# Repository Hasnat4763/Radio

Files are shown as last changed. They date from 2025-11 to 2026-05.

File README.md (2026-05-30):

# Akash Chowa DX

Akash Chowa DX is a SW/MW/LW receiver designed based on the Si4735 Radio receiver IC paired with the RP2040 Zero Dev board.

# Why did I build it?

I had an affection towards Radios from childhood. I sometimes try to receive SW stations on my 5$ budget radio I had gotten from a local store. But It does not work that efficiently and I needed a better receiver.
Also the radio I currently have can not demodulate SSB (Single Sideband) and RDS transmitted by modern FM stations. So I designed it to fulfill my own requirements. It also helped me learn new things like impedance control.

# Gallery

Here are some pictures of what I designed

# Schematic

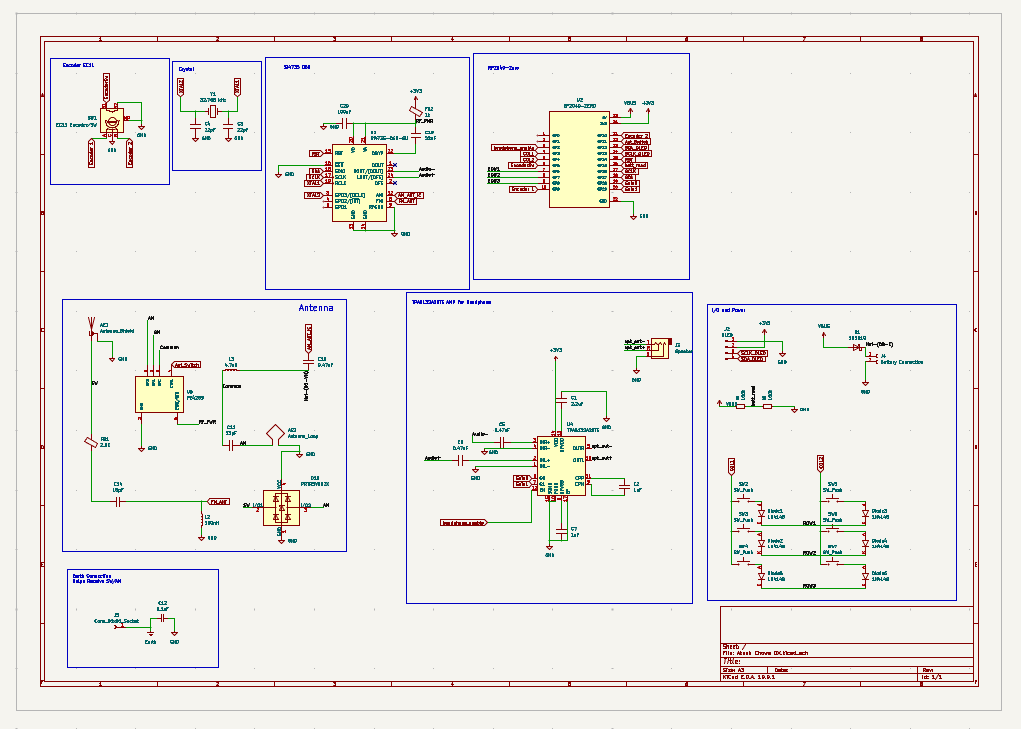
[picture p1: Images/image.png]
Schematic


# PCB

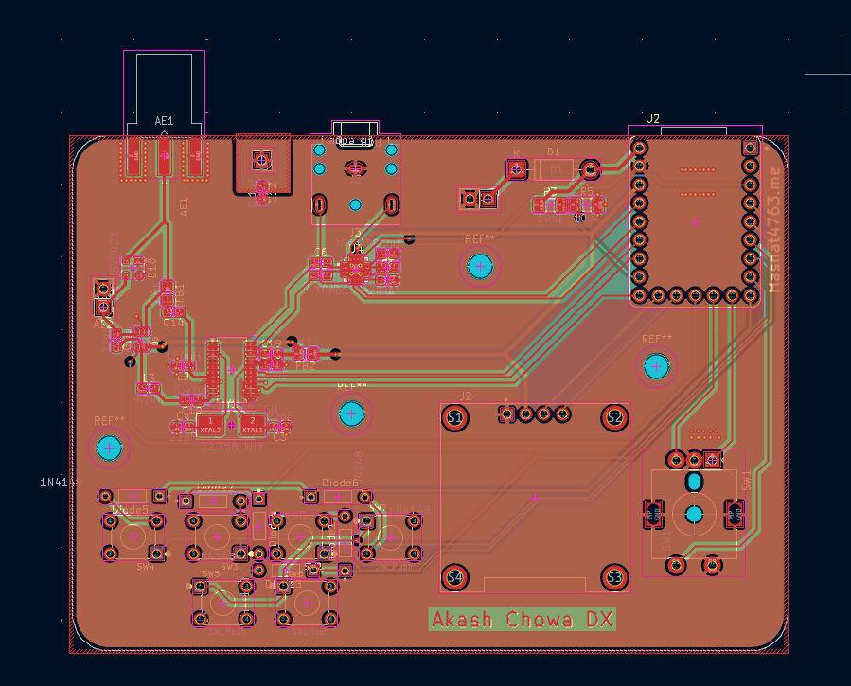
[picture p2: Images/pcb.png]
PCB


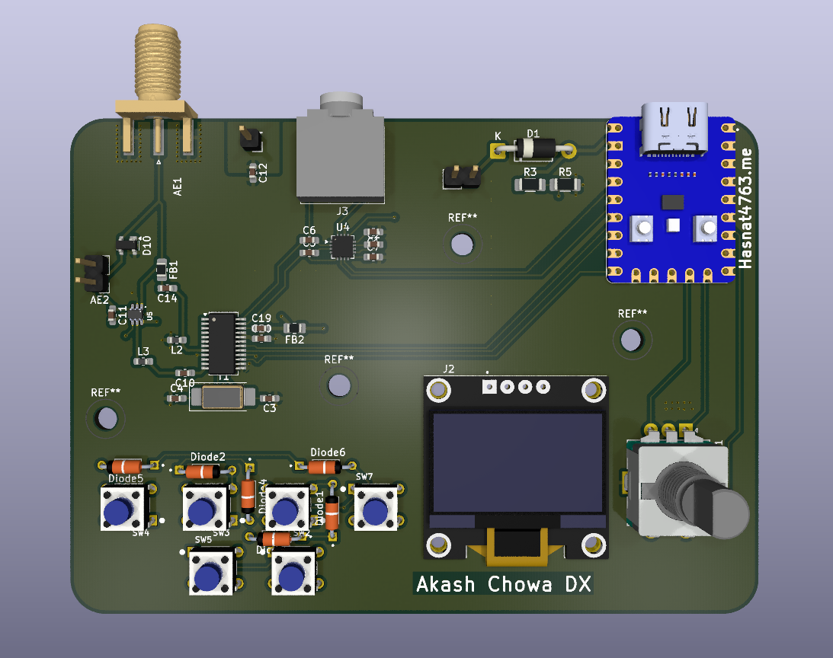
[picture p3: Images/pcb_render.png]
PCB 3D render


# CAD

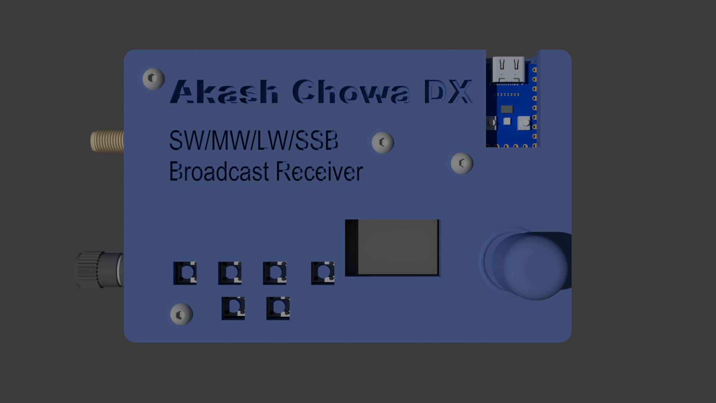
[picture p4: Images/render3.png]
CAD 3D render


Base of the case

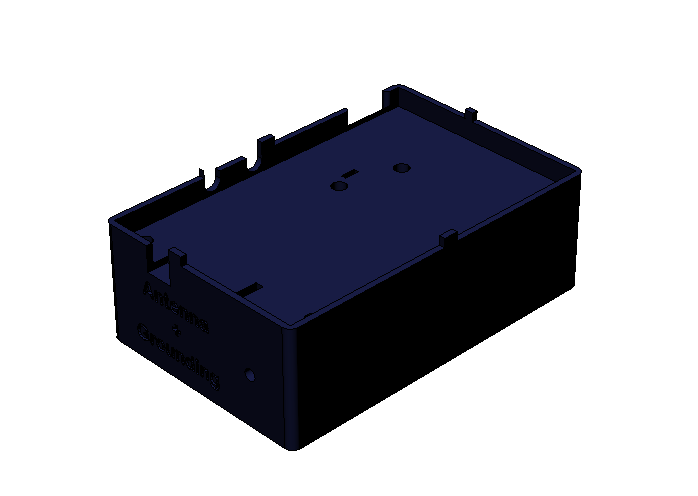
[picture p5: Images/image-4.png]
base


battery cover

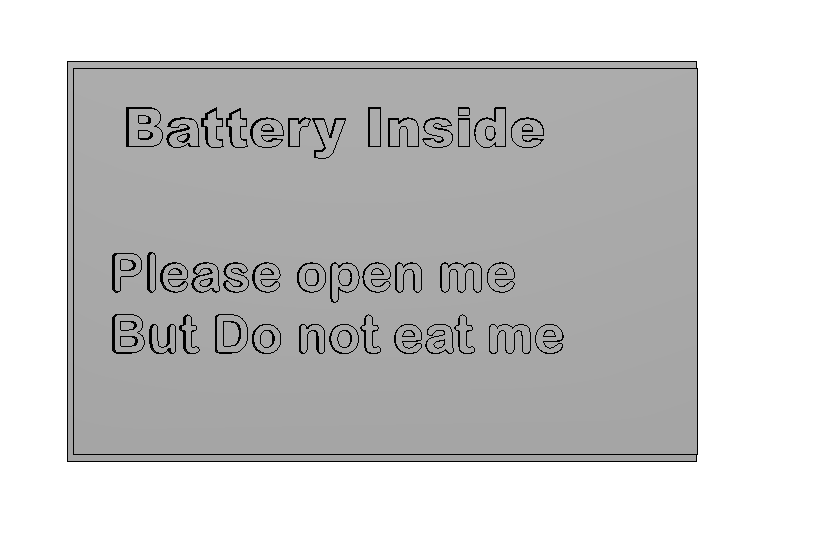
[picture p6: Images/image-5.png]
battery cover


top cover

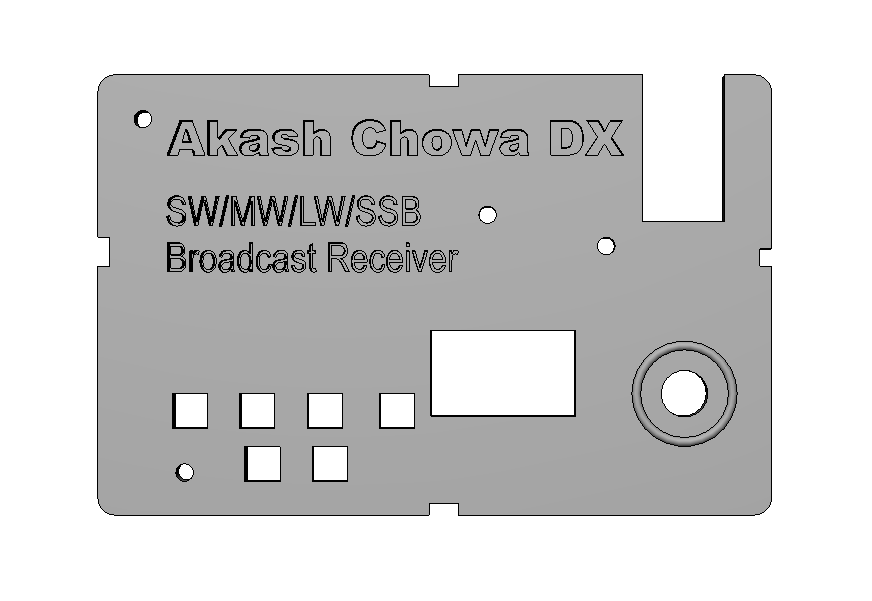
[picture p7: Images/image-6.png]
top cover


# BOM (in progress)

| Item | Quantity | Price | Link |
|---|---|---|---|
| Waveshare RP2040 Zero | 1 | $5.86 | [Link](https://www.aliexpress.com/item/1005009026492881.html) |
| 1N5819 Diode | 100 | $5.49 | [Link](https://www.aliexpress.com/item/1005010374297754.html) |
| 1N4148 Diode | 100 | $4.43 | [Link](https://www.aliexpress.com/item/1005010373909049.html) |
| SSD1306 OLED Display | 1 | $5.33 | [Link](https://www.aliexpress.com/item/1005006141235306.html) |
| EC 11 Encoder with Push Button Half Handle 20MM Shaft | 5 | $6.31 | [Link](https://www.aliexpress.com/item/1005005983134515.html) |
| Si4735 D60 GU | 1 | $15.52  | [Link](https://www.aliexpress.com/item/1005007992766374.html)|
| PE4259 | 20 | $4.96  | [Link](https://www.aliexpress.com/item/32860670352.html)|
| 32.768 kHz Crystal SMD | 10 | $5.01  | [Link](https://www.aliexpress.com/item/1005007548931959.html)|
| CM1213A-01SO | 20 | $6.09  | [Link](https://www.aliexpress.com/item/1005010362089021.html)|
| PAM8302A | 10 | $4.15  | [Link](https://www.aliexpress.com/item/1005011807938839.html)|
| LM4910MM | 5 | $11.43  | [Link](https://www.aliexpress.com/item/1005008963839272.html)|
| 2.5K Ferrite Bead | 100 | $1.63  | [Link](https://www.aliexpress.com/item/1005009841998170.html)|
| 1K Ferrite Bead | 100 | $1.70  | [Link](https://www.aliexpress.com/item/1005009841998170.html)|
| 100uF, 10uF, 100nF, 22pF, 1uF, 0.47uF, 33pF, 18pF, 22nF Capacitor Pack | 720 | $6.21  | [Link](https://www.aliexpress.com/item/1005006124283234.html)|
| 100 ohm Resistor 1206 | 100 | $1.61  | [Link](https://www.aliexpress.com/item/1005011924690352.html)|
| 20k ohm Resistor 1206 | 100 | $1.61  | [Link](https://www.aliexpress.com/item/1005011924690352.html)|
| 100k ohm Resistor 1206 | 100 | $1.61  | [Link](https://www.aliexpress.com/item/1005011924690352.html)|
| SMA connector Edge Mount | 5 | $5.32  | [Link](https://www.aliexpress.com/item/1005007424915378.html)|
| 180nH Inductor 0603 | 100 | $1.33  | [Link](https://www.aliexpress.com/item/1005004900337516.html)|
| 4.7uH Inductor 0603 | 100 | $1.33  | [Link](https://www.aliexpress.com/item/1005004900337516.html)|
| Tactile Switches Push buttons | 20 | $4.12  | [Link](https://www.aliexpress.com/item/1005006046180384.html)|
| 18650 Lithium Battery | 2 | BDT 510 (~$4.16)  | [Link](https://store.roboticsbd.com/battery-charger/983-18650-generic-37v-li-ion-battery-standard-quality-flat-top-solderable-robotics-bangladesh.html)|
| TP4056 BMS | 1 | $4.02 | [Link](https://www.aliexpress.com/item/1005009635476640.html)|
| Rocker Switch | 5 | $5.20  | [Link](https://www.aliexpress.com/item/1005008778176373.html)|
| Binding Post | 5 | $6.00 | [Link](https://www.aliexpress.com/item/1005008274414247.html)|
| Headphone Connector | 10 | $4.45 | [Link](https://www.aliexpress.com/item/32871877936.html)|
| M3 Heat Set Inserts | 30 | $6.13 | [Link](https://www.aliexpress.com/item/1005006071488810.html) |
| M3 Fasteners | 50 | $6.28 | [Link](https://www.aliexpress.com/item/1005011845940916.html) |
| Top Case | 1 | Printing Legion |  |
| Bottom Case | 1 | Printing Legion |  |
| Battery Cover | 1 | Printing Legion | |
| PCB | 5 | $27.67 | JLCPCB |

# Build/Usage Instruction

For impedance control, while ordering from JLCPCB, select the JLC04161H-7628 layer stackup. Also better to import this to the Easyeda Pro and then order as that can get you a few extra discounts.

For ordering parts, you can find most components in LCSC but some components may not be available in LCSC so it needs to be bought from 3rd party stores like aliexpress/alibaba.

For the AM antenna its better to source it from an old broken radio, as its hard to find ferrite antennas online. 

You need a 9:1 Balun to match the impedance of the SMA feed with the long wire antenna you are using.

Never use the Radio while its plugged into the Mains as it introduces extra noise.

For grounding you may be able to just lay the wire parallel to the ground for a few meters.

# Flashing the firmware

To flash the firmware, you first need to add the board to your arduino IDE.

After getting into the Arduino IDE, Go to Preference
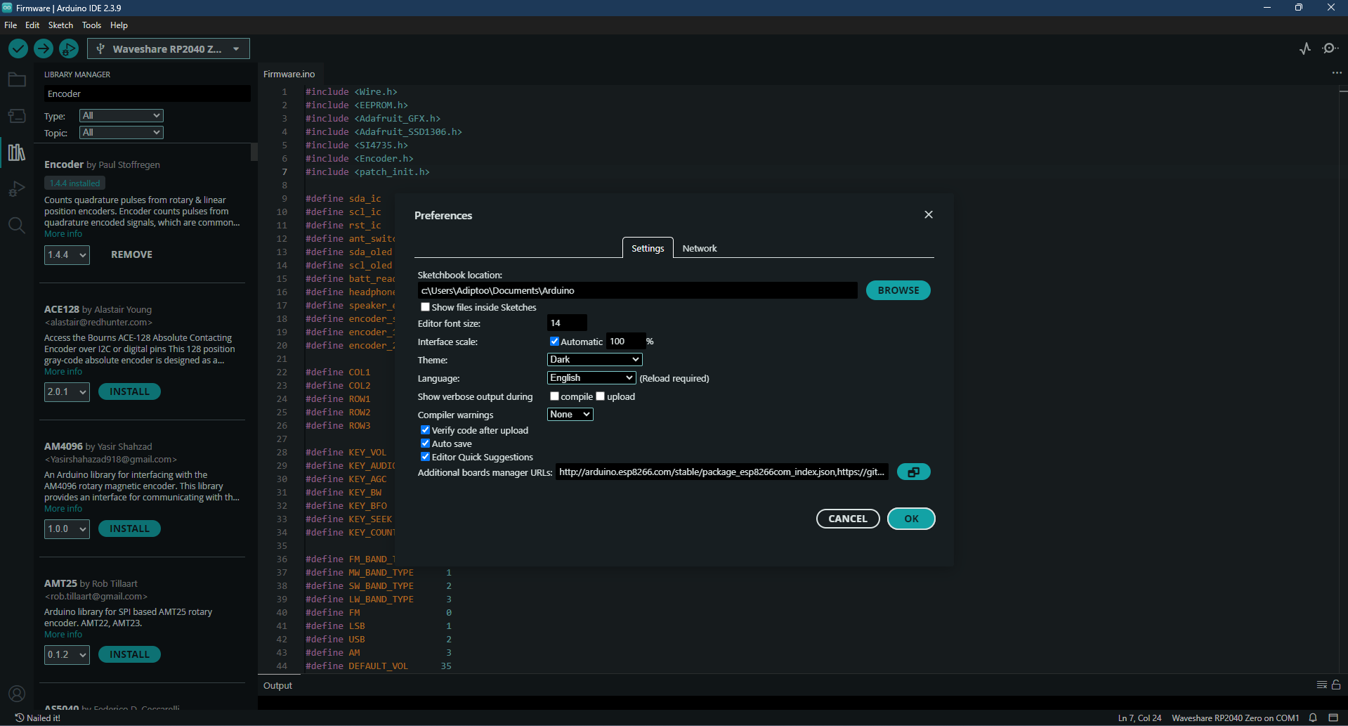
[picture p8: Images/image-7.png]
Preference


Now click on the additional board manager URL and add ```https://github.com/earlephilhower/arduino-pico/releases/download/4.5.2/package_rp2040_index.json```
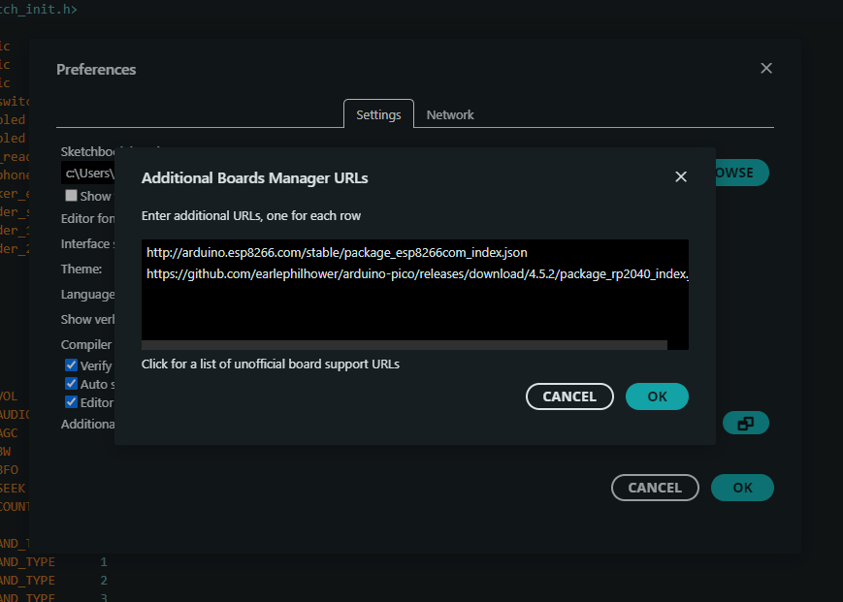
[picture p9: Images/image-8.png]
Board manager URL


Now go to boards manager and search RP2040 and download this library
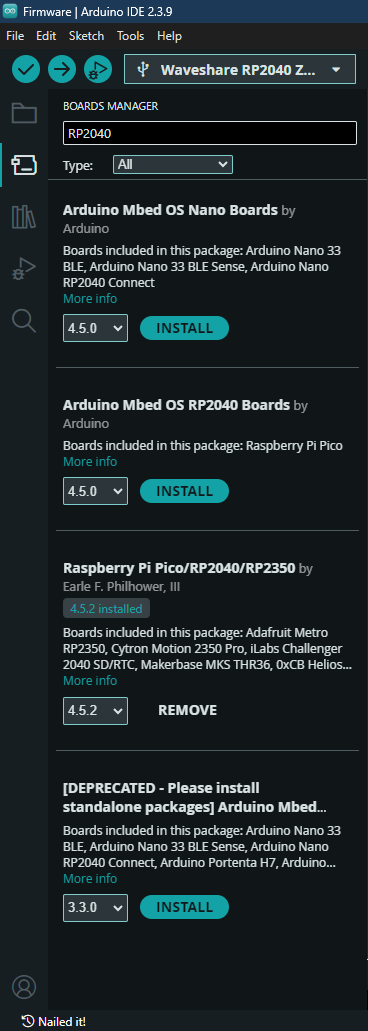
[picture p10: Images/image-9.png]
Boards


Now you can select the MCU as the waveshare RP2040 zero.

After that you need a few libraries
Si4735 library
Adafruit SSD1306 library
Adafruit GFX library
and the Rotary Encoder Library by Paul Stoffregen

Then you can flash the firmware.

For more details on the Si4735 follow the directions in [Si4735 Arduino Library](https://pu2clr.github.io/SI4735/) here.

# Zine 

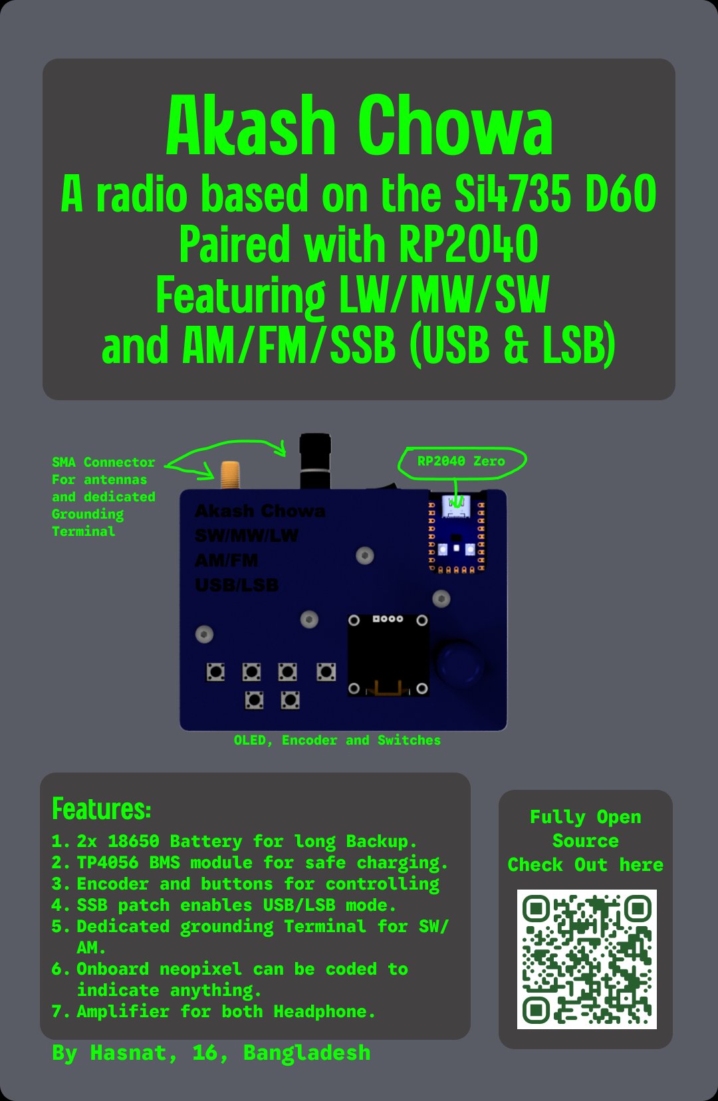
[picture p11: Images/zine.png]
Zine Poster


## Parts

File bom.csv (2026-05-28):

Item | Quantity | Unit Price (USD) | Total Price (USD) | Link
Waveshare RP2040 Zero | 1 | 5.86 | 5.86 | https://www.aliexpress.com/item/1005009026492881.html
1N5819 Diode | 100 | 0.0549 | 5.49 | https://www.aliexpress.com/item/1005010374297754.html
1N4148 Diode | 100 | 0.0443 | 4.43 | https://www.aliexpress.com/item/1005010373909049.html
SSD1306 OLED Display | 1 | 5.33 | 5.33 | https://www.aliexpress.com/item/1005006141235306.html
EC11 Encoder with Push Button Half Handle 20MM Shaft | 5 | 1.262 | 6.31 | https://www.aliexpress.com/item/1005005983134515.html
Si4735 D60 GU | 1 | 15.52 | 15.52 | https://www.aliexpress.com/item/1005007992766374.html
PE4259 | 20 | 0.248 | 4.96 | https://www.aliexpress.com/item/32860670352.html
32.768 kHz Crystal SMD | 10 | 0.501 | 5.01 | https://www.aliexpress.com/item/1005007548931959.html
CM1213A-01SO | 20 | 0.3045 | 6.09 | https://www.aliexpress.com/item/1005010362089021.html
PAM8302A | 10 | 0.415 | 4.15 | https://www.aliexpress.com/item/1005011807938839.html
LM4910MM | 5 | 2.286 | 11.43 | https://www.aliexpress.com/item/1005008963839272.html
2.5K Ferrite Bead | 100 | 0.0163 | 1.63 | https://www.aliexpress.com/item/1005009841998170.html
1K Ferrite Bead | 100 | 0.017 | 1.70 | https://www.aliexpress.com/item/1005009841998170.html
Capacitor Pack (100uF,10uF,100nF,22pF,1uF,0.47uF,33pF,18pF,22nF) | 720 | 0.00863 | 6.21 | https://www.aliexpress.com/item/1005006124283234.html
100 ohm Resistor 1206 | 100 | 0.0161 | 1.61 | https://www.aliexpress.com/item/1005011924690352.html
20k ohm Resistor 1206 | 100 | 0.0161 | 1.61 | https://www.aliexpress.com/item/1005011924690352.html
100k ohm Resistor 1206 | 100 | 0.0161 | 1.61 | https://www.aliexpress.com/item/1005011924690352.html
SMA Connector Edge Mount | 5 | 1.064 | 5.32 | https://www.aliexpress.com/item/1005007424915378.html
180nH Inductor 0603 | 100 | 0.0133 | 1.33 | https://www.aliexpress.com/item/1005004900337516.html
4.7uH Inductor 0603 | 100 | 0.0133 | 1.33 | https://www.aliexpress.com/item/1005004900337516.html
Tactile Switches Push Buttons | 20 | 0.206 | 4.12 | https://www.aliexpress.com/item/1005006046180384.html
18650 Lithium Battery | 2 | 2.08 | 4.16 | https://store.roboticsbd.com/battery-charger/983-18650-generic-37v-li-ion-battery-standard-quality-flat-top-solderable-robotics-bangladesh.html
TP4056 BMS | 1 | 4.02 | 4.02 | https://www.aliexpress.com/item/1005009635476640.html
Rocker Switch | 5 | 1.04 | 5.20 | https://www.aliexpress.com/item/1005008778176373.html
Binding Post | 5 | 1.20 | 6.00 | https://www.aliexpress.com/item/1005008274414247.html
Headphone Connector | 10 | 0.445 | 4.45 | https://www.aliexpress.com/item/32871877936.html
M3 Heat Set Inserts | 30 | 0.2043 | 6.13 | https://www.aliexpress.com/item/1005006071488810.html
M3 Fasteners | 50 | 0.1256 | 6.28 | https://www.aliexpress.com/item/1005011845940916.html
Top Case | 1 | N/A (Printing Legion) | N/A
Bottom Case | 1 | N/A (Printing Legion) | N/A
Battery Cover | 1 | N/A (Printing Legion) | N/A
PCB (JLCPCB - 5 boards) | 5 | 5.534 | 27.67 | JLCPCB

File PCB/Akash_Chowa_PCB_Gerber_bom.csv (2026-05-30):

Designator | Footprint | Quantity | Value | LCSC Part #
AE1 | SMA_Amphenol_132289_EdgeMount | 1 | Antenna_Shield
AE2 | PinHeader_1x02_P2.54mm_Vertical | 1 | Antenna_Loop
C1 | 0603 | 1 | 2.2uF
C10, C5, C6 | 0603 | 3 | 0.47uF
C11 | 0603 | 1 | 33pF
C12 | 0603 | 1 | 0.1uF
C14 | 0603 | 1 | 18pF
C19 | 0603 | 1 | 22nF
C2, C7 | 0603 | 2 | 1uF
C20 | 0603 | 1 | 100nF
C3, C4 | 0603 | 2 | 22pF
D1 | D_DO-41_SOD81_P10.16mm_Horizontal | 1 | 1N5819
D10 | SOT-143 | 1 | PRTR5V0U2X
DIODE1, DIODE2, DIODE3, DIODE4, DIODE5, DIODE6 | DIOAD753W49L380D172B | 6 | 1N4148
FB1 | 0805 | 1 | 2.5K
FB2 | 0805 | 1 | 1k
J2 | MODULE_DM-OLED096-636 | 1 | OLED
J3 | Jack_3.5mm_CUI_SJ1-3523N_Horizontal | 1 | Speaker
J4 | PinHeader_1x02_P2.54mm_Vertical | 1 | Battery Connection
J5 | PinHeader_1x01_P2.54mm_Vertical | 1 | Conn_01x01_Socket
L2 | 0603 | 1 | 180nH
L3 | 0603 | 1 | 4.7uH
R3, R5 | 1206 | 2 | 100k
SW1 | RotaryEncoder_Alps_EC11E-Switch_Vertical_H20mm_MountingHoles | 1 | EC11 Encoder/SW
SW2, SW3, SW4, SW5, SW6, SW7 | SW_FSM8JH | 6 | SW_Push
U1 | SSOP-24_3.9x8.7mm_P0.635mm | 1 | Si4735-D60-GU
U2 | MODULE_RP2040-ZERO | 1 | RP2040-ZERO
U4 | WQFN-16-1EP_3x3mm_P0.5mm_EP1.6x1.6mm_ThermalVias | 1 | TPA6132A2RTE
U5 | SOT65P215X110-6N | 1 | PE4259
Y1 | Crystal_SMD_0603-2Pin_6.0x3.5mm_HandSoldering | 1 | 32.768 kHz

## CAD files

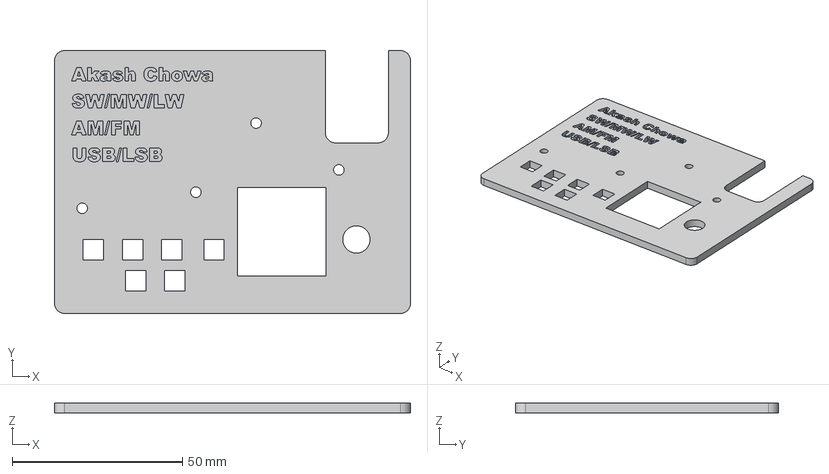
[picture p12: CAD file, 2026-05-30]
CAD/Akash Chowa Top Cover.step
104.5 x 77.2 x 3.00 mm

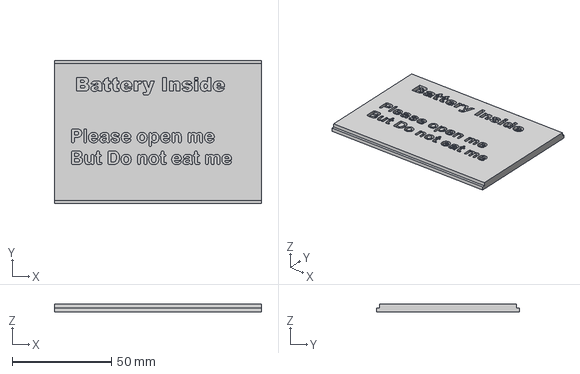
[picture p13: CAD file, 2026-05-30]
CAD/Akash Chowa Battery Cover.step
104.5 x 72.2 x 4.00 mm

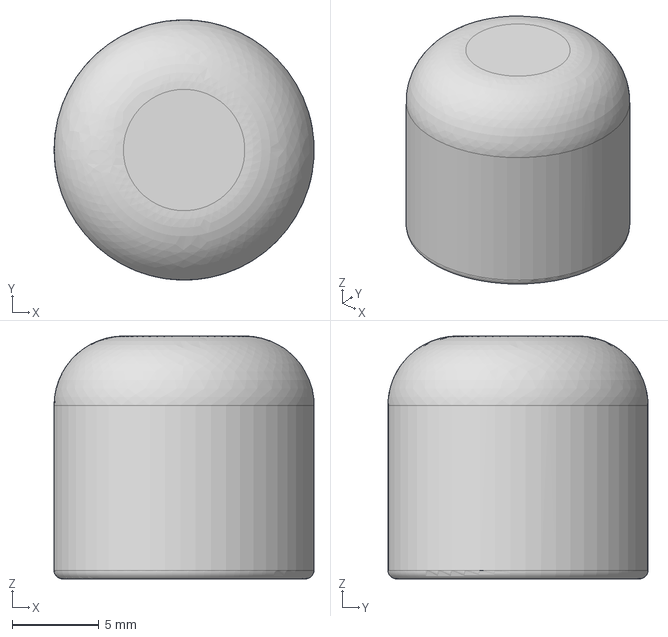
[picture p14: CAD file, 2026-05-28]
CAD/Knob Cap.step
15.0 x 15.0 x 14.0 mm

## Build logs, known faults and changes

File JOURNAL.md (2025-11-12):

<!--
  ===================    !!READ THIS NOTICE!!   ====================
  DO NOT edit this file manually. Your changes WILL BE OVERWRITTEN!
  This journal is auto generated and updated by Hack Club Blueprint.
  To edit this file, please edit your journal entries on Blueprint.
  ==================================================================
-->

## 11/5/2025 - Started with the schematic  

I got info about the Si4844 a long time ago so today I got the Datasheet and followed the basic schematic that was given to draw one for my own project
I still need to do some more stuff in the schematic


## 11/6/2025 - Did the basic part of PCB  

This is an RF pcb which I haven't designed any
So I did the basic placement of components that I think are right

Gonna ask an engineer to take a look later

## 11/10/2025 10 AM - Made the PCB a bit compact  

I saw there was more space so I put the components a bit together but still far away from each other to counter noises from the digital circuits
I also changed the potentiometer footprint to a horizontal one

Also increased power trace width to 0.4mm and increased the area below where I will glue the ferrite antenna

I was also busy with siege project so this journal is containing stuff I did in multiple days

Will start working on the case soon  

## 11/10/2025 9 PM - Reduced PCB Size  

I reduced the size from around 60 x 180 mm to 55 x 65 mm
I had a lot of free space so souptik suggested to reduced the size
he was insisting on reducing it to 30x30



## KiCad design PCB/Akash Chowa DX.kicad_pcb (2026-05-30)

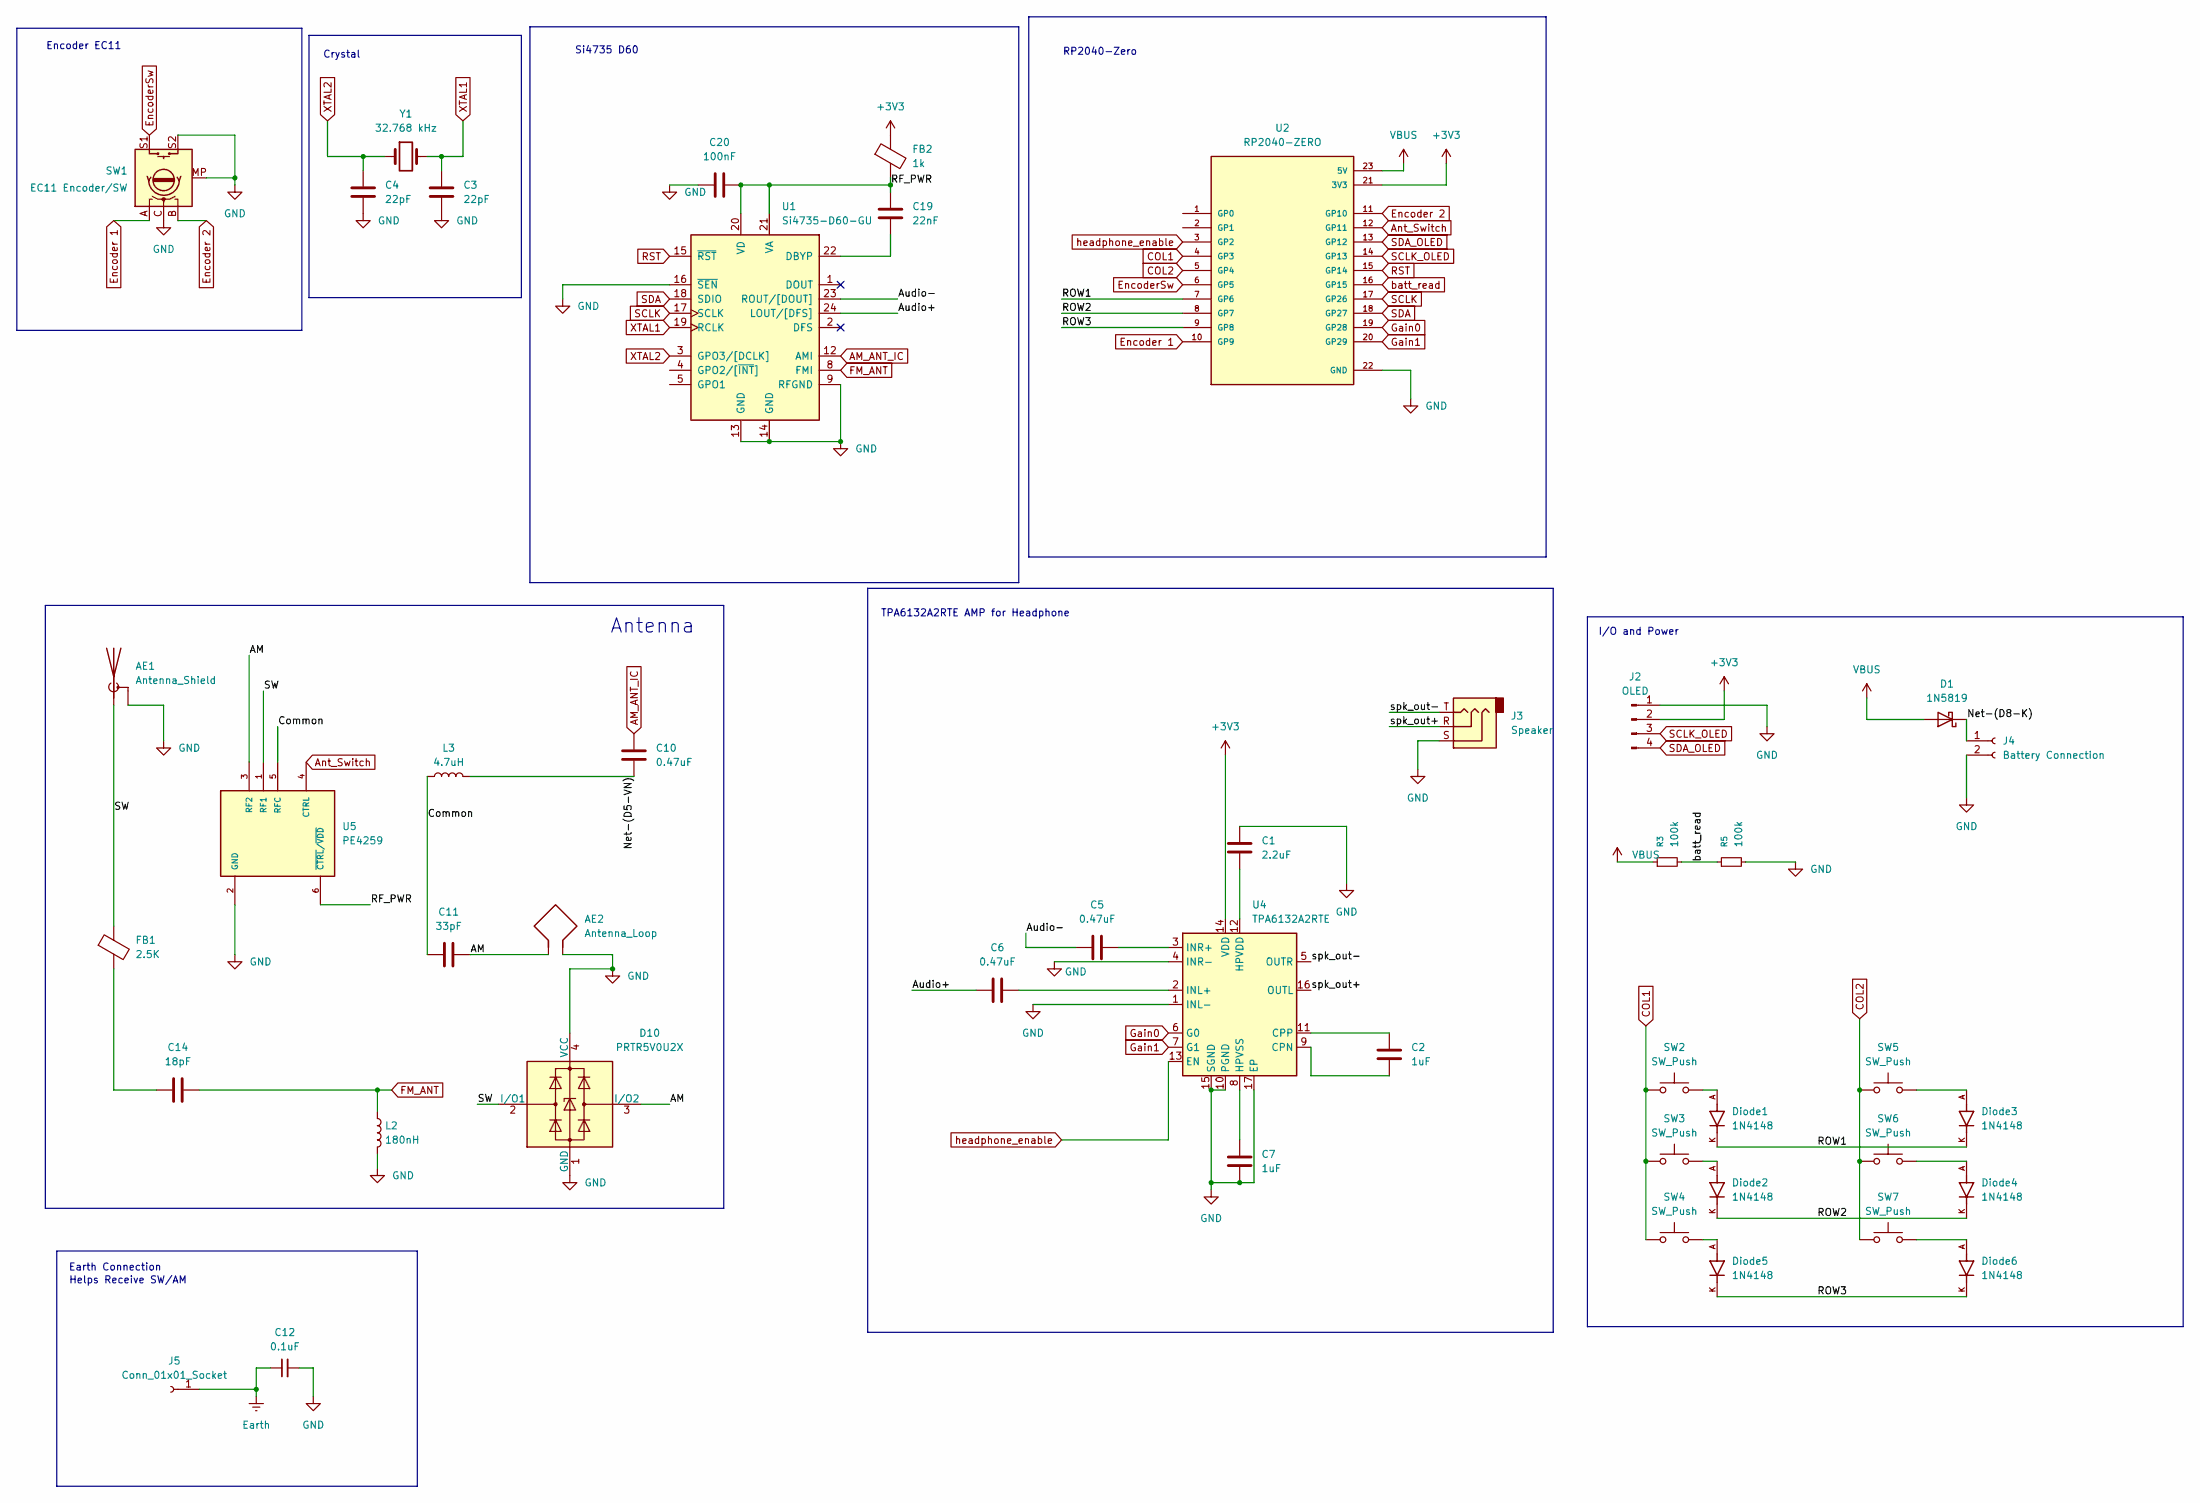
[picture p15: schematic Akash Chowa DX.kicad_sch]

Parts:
AE1: Antenna_Shield; SMA_Amphenol_132289_EdgeMount
AE2: Antenna_Loop; PinHeader_1x02_P2.54mm_Vertical
C1: 2.2uF; C_0603_1608Metric_Pad1.08x0.95mm_HandSolder
C2, C7: 1uF; C_0603_1608Metric_Pad1.08x0.95mm_HandSolder
C3, C4: 22pF; C_0603_1608Metric_Pad1.08x0.95mm_HandSolder
C5, C6, C10: 0.47uF; C_0603_1608Metric_Pad1.08x0.95mm_HandSolder
C11: 33pF; C_0603_1608Metric_Pad1.08x0.95mm_HandSolder
C12: 0.1uF; C_0603_1608Metric_Pad1.08x0.95mm_HandSolder
C14: 18pF; C_0603_1608Metric_Pad1.08x0.95mm_HandSolder
C19: 22nF; C_0603_1608Metric_Pad1.08x0.95mm_HandSolder
C20: 100nF; C_0603_1608Metric_Pad1.08x0.95mm_HandSolder
D1: 1N5819; D_DO-41_SOD81_P10.16mm_Horizontal
D10: PRTR5V0U2X; SOT-143
Diode1, Diode2, Diode3, Diode4, Diode5, Diode6: 1N4148; DIOAD753W49L380D172B; PARTREV 5
FB1: 2.5K; R_0805_2012Metric_Pad1.20x1.40mm_HandSolder
FB2: 1k; R_0805_2012Metric_Pad1.20x1.40mm_HandSolder
J2: OLED; MODULE_DM-OLED096-636
J3: Speaker; Jack_3.5mm_CUI_SJ1-3523N_Horizontal
J4: Battery Connection; PinHeader_1x02_P2.54mm_Vertical
J5: Conn_01x01_Socket; PinHeader_1x01_P2.54mm_Vertical
L2: 180nH; L_0603_1608Metric_Pad1.05x0.95mm_HandSolder
L3: 4.7uH; L_0603_1608Metric_Pad1.05x0.95mm_HandSolder
R3, R5: 100k; R_1206_3216Metric_Pad1.30x1.75mm_HandSolder
SW1: EC11 Encoder/SW; RotaryEncoder_Alps_EC11E-Switch_Vertical_H20mm_MountingHoles
SW2, SW3, SW4, SW5, SW6, SW7: SW_Push; SW_FSM8JH
U1: Si4735-D60-GU; SSOP-24_3.9x8.7mm_P0.635mm
U2: RP2040-ZERO; MODULE_RP2040-ZERO; PARTREV NA
U4: TPA6132A2RTE; WQFN-16-1EP_3x3mm_P0.5mm_EP1.6x1.6mm_ThermalVias
U5: PE4259; SOT65P215X110-6N
Y1: 32.768 kHz; Crystal_SMD_0603-2Pin_6.0x3.5mm_HandSoldering

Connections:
+3V3: FB2.1, J2.2, U2.21 (3V3), U4.14 (VDD)
/AM: AE2.1, C11.1, D10.3 (I/O2), U5.3 (RF2)
/Audio+: C6.1, U1.24 (LOUT/[DFS])
/Audio-: C5.1, U1.23 (ROUT/[DOUT])
/Common: C11.2, L3.1, U5.5 (RFC)
/Net-(D5-VN): C10.2, L3.2
/Net-(D8-K): D1.1 (K), J4.1
/RF_PWR: C19.2, C20.1, FB2.2, U1.20 (VD), U1.21 (VA), U5.6 (~CTRL/~VDD)
/ROW1: Diode1.K, Diode3.K, U2.7 (GP6)
/ROW2: Diode2.K, Diode4.K, U2.8 (GP7)
/ROW3: Diode5.K, Diode6.K, U2.9 (GP8)
/SW: AE1.1 (A), D10.2 (I/O1), FB1.1, U5.1 (RF1)
/spk_out+: J3.R, U4.16 (OUTL)
/spk_out-: J3.T, U4.5 (OUTR)
AM_ANT_IC: C10.1, U1.12 (AMI)
Ant_Switch: U2.12 (GP11), U5.4 (CTRL)
COL1: SW2.1, SW3.1, SW4.1, U2.4 (GP3)
COL2: SW5.1, SW6.1, SW7.1, U2.5 (GP4)
Earth: C12.1, J5.1 (Pin_1_1)
Encoder 1: SW1.A, U2.10 (GP9)
Encoder 2: SW1.B, U2.11 (GP10)
EncoderSw: SW1.S1, U2.6 (GP5)
FM_ANT: C14.1, L2.1, U1.8 (FMI)
GND: AE1.2 (Shield), AE2.2, C1.1, C3.1, C4.1, C7.2, C12.2, C20.2, D10.1 (GND), D10.4 (VCC), J2.1, J3.S, J4.2, L2.2, R5.2, SW1.C, SW1.MP, SW1.S2, U1.9 (RFGND), U1.13 (GND), U1.14 (GND), U1.16 (~SEN), U2.22 (GND), U4.1 (INL-), U4.4 (INR-), U4.10 (PGND), U4.15 (SGND), U4.17 (EP), U5.2 (GND)
Gain0: U2.19 (GP28), U4.6 (G0)
Gain1: U2.20 (GP29), U4.7 (G1)
unnamed: C14.2, FB1.2
unnamed: Diode1.A, SW2.2
unnamed: Diode2.A, SW3.2
unnamed: Diode3.A, SW5.2
unnamed: Diode4.A, SW6.2
unnamed: Diode5.A, SW4.2
unnamed: Diode6.A, SW7.2
unnamed: C19.1, U1.22 (DBYP)
unnamed: C2.2, U4.9 (CPN)
unnamed: C2.1, U4.11 (CPP)
unnamed: C1.2, U4.12 (HPVDD)
unnamed: C7.1, U4.8 (HPVSS)
unnamed: C6.2, U4.2 (INL+)
unnamed: C5.2, U4.3 (INR+)
RST: U1.15 (~RST), U2.15 (GP14)
SCLK: U1.17 (SCLK), U2.17 (GP26)
SCLK_OLED: J2.3, U2.14 (GP13)
SDA: U1.18 (SDIO), U2.18 (GP27)
SDA_OLED: J2.4, U2.13 (GP12)
VBUS: D1.2 (A), R3.1, U2.23 (5V)
XTAL1: C3.2, U1.19 (RCLK), Y1.2
XTAL2: C4.2, U1.3 (GPO3/[DCLK]), Y1.1
batt_read: R3.2, R5.1, U2.16 (GP15)
headphone_enable: U2.3 (GP2), U4.13 (EN)

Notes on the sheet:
Antenna
Helps Receive SW/AM
Si4735 D60
RP2040-Zero
Encoder EC11
Earth Connection
I/O and Power
TPA6132A2RTE AMP for Headphone
Crystal

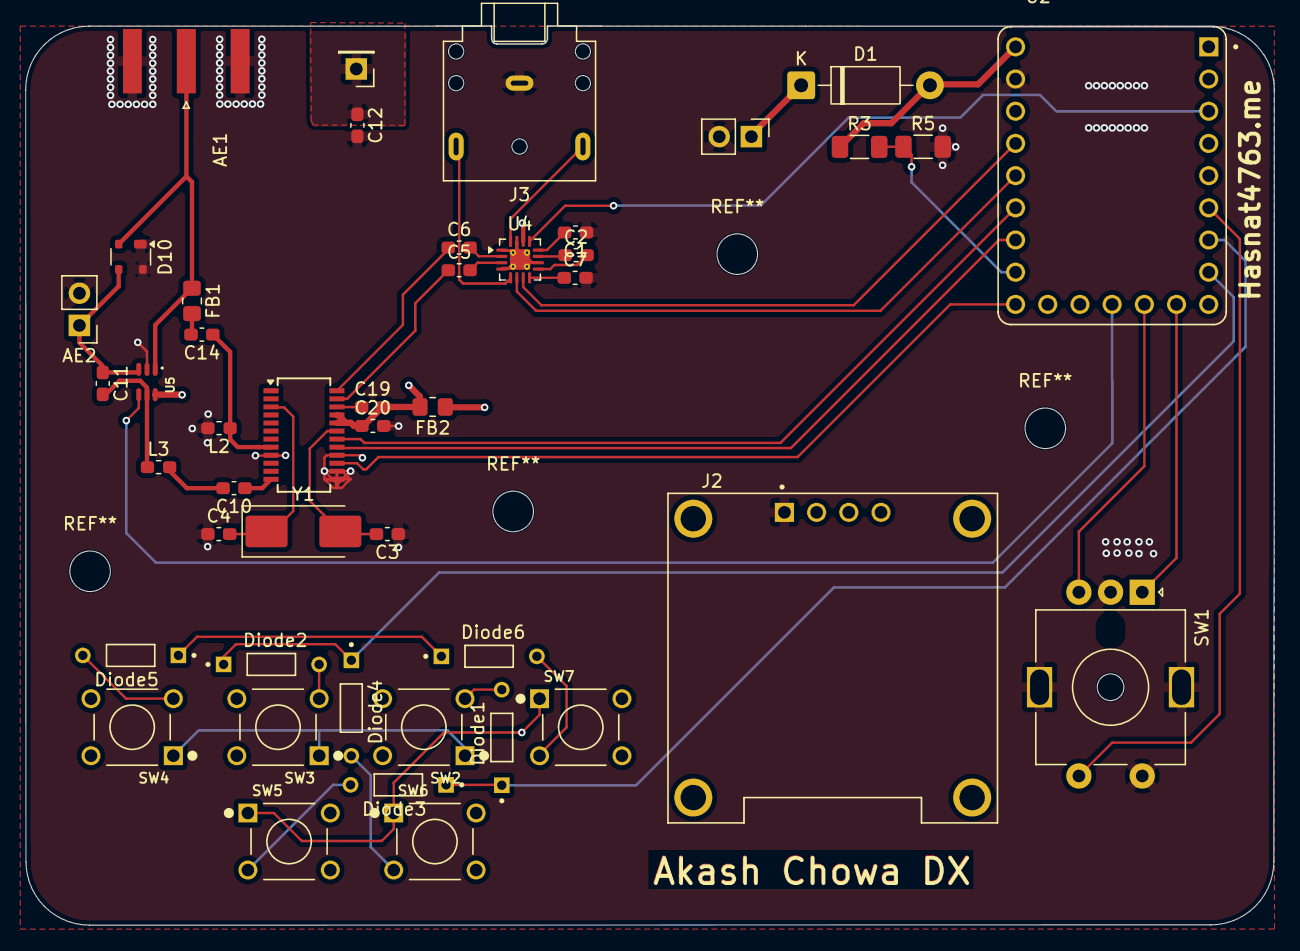
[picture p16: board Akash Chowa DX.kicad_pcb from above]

Board: 4 copper layers, 98.5 x 70.9 mm, 45 parts (0 on the bottom side), 50 nets.

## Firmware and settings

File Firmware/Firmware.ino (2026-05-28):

#include <Wire.h>
#include <EEPROM.h>
#include <Adafruit_GFX.h>
#include <Adafruit_SSD1306.h>
#include <SI4735.h>
#include <Encoder.h>
#include <patch_init.h>

#define sda_ic            26
#define scl_ic            27
#define rst_ic            14
#define ant_switch        11
#define sda_oled          12
#define scl_oled          13
#define batt_read         15
#define headphone_enable  28
#define speaker_enable    29
#define encoder_sw         5
#define encoder_1          9
#define encoder_2         10

#define COL1               3
#define COL2               4
#define ROW1               6
#define ROW2               7
#define ROW3               8

#define KEY_VOL       0
#define KEY_AUDIO     1
#define KEY_AGC       2
#define KEY_BW        3
#define KEY_BFO       4
#define KEY_SEEK      5
#define KEY_COUNT     6

#define FM_BAND_TYPE      0
#define MW_BAND_TYPE      1
#define SW_BAND_TYPE      2
#define LW_BAND_TYPE      3
#define FM                0
#define LSB               1
#define USB               2
#define AM                3
#define DEFAULT_VOL      35
#define LONG_PRESS_MS   600
#define DEBOUNCE_MS      50
#define RSSI_INTERVAL  1800
#define OLED_ADDR      0x3C

float   battVoltage    = 0.0;
uint8_t battPercent    = 0;
unsigned long lastBattTime = 0;
#define BATT_INTERVAL  10000
#define BATT_R1        100000
#define BATT_R2        100000
#define BATT_MAX       4.2
#define BATT_MIN       3.0
#define ADC_RES        4095.0
#define ADC_VREF       3.3

const uint16_t size_content = sizeof(ssb_patch_content);

const char *bandwidthSSB[] = {"1.2", "2.2", "3.0", "4.0", "0.5", "1.0"};
const char *bandwidthAM[]  = {"6",   "4",   "3",   "2",   "1",   "1.8", "2.5"};
uint8_t bwIdxSSB = 2;
uint8_t bwIdxAM  = 1;

typedef struct {
  uint8_t  bandType;
  uint16_t minimumFreq;
  uint16_t maximumFreq;
  uint16_t currentFreq;
  uint16_t currentStep;
} Band;

Band band[] = {
  {FM_BAND_TYPE,  8400, 10800, 10390, 10},
  {LW_BAND_TYPE,   100,   510,   300,  1},
  {MW_BAND_TYPE,   520,  1720,   810, 10},
  {SW_BAND_TYPE,  1800,  3500,  1900,  1},
  {SW_BAND_TYPE,  3500,  4500,  3700,  1},
  {SW_BAND_TYPE,  4500,  5500,  4850,  5},
  {SW_BAND_TYPE,  5600,  6300,  6000,  5},
  {SW_BAND_TYPE,  6800,  7800,  7200,  5},
  {SW_BAND_TYPE,  9200, 10000,  9600,  5},
  {SW_BAND_TYPE, 10000, 11000, 10100,  1},
  {SW_BAND_TYPE, 11200, 12500, 11940,  5},
  {SW_BAND_TYPE, 13400, 13900, 13600,  5},
  {SW_BAND_TYPE, 14000, 14500, 14200,  1},
  {SW_BAND_TYPE, 15000, 15900, 15300,  5},
  {SW_BAND_TYPE, 17200, 17900, 17600,  5},
  {SW_BAND_TYPE, 18000, 18300, 18100,  1},
  {SW_BAND_TYPE, 21000, 21900, 21200,  1},
  {SW_BAND_TYPE, 24890, 26200, 24940,  1},
  {SW_BAND_TYPE, 26200, 27900, 27500,  1},
  {SW_BAND_TYPE, 28000, 30000, 28400,  1}
};
const int lastBand = (sizeof(band) / sizeof(Band)) - 1;

const char *bandModeDesc[] = {"FM", "LSB", "USB", "AM"};
uint8_t  currentMode  = FM;
uint8_t  volume       = DEFAULT_VOL;
uint8_t  rssi         = 0;
int      bandIdx      = 0;
int      currentBFO   = 0;
int      previousBFO  = 0;
uint16_t currentFreq;
uint16_t previousFreq;
uint16_t currentStep  = 10;
bool     ssbLoaded    = false;
bool     disableAgc   = true;
bool     isMuted      = false;

enum AudioOutput { OUTPUT_SPEAKER, OUTPUT_HEADPHONE };
AudioOutput currentOutput = OUTPUT_SPEAKER;

bool     keyState[KEY_COUNT]     = {false};
bool     keyHeld[KEY_COUNT]      = {false};
bool     keyWasHeld[KEY_COUNT]   = {false};
unsigned long keyPressTime[KEY_COUNT] = {0};
unsigned long lastKeyEvent[KEY_COUNT] = {0};

const uint8_t rowPins[] = {ROW1, ROW2, ROW3};
const uint8_t colPins[] = {COL1, COL2};

long encoderOldPos = -999;
int  encoderDelta  = 0;
unsigned long lastEncClick = 0;

unsigned long lastRSSITime = 0;

Adafruit_SSD1306 display(128, 64, &Wire, -1);
SI4735           si4735;
Encoder          knob(encoder_1, encoder_2);

void scanMatrix() {
  unsigned long now = millis();

  for (int r = 0; r < 3; r++) {
    for (int i = 0; i < 3; i++)
      pinMode(rowPins[i], (i == r) ? OUTPUT : INPUT);
    digitalWrite(rowPins[r], LOW);
    delayMicroseconds(10);

    for (int c = 0; c < 2; c++) {
      int keyIdx = r * 2 + c;
      bool pressed = (digitalRead(colPins[c]) == LOW);

      if (pressed && !keyState[keyIdx]) {
        if (now - lastKeyEvent[keyIdx] > DEBOUNCE_MS) {
          keyState[keyIdx]    = true;
          keyPressTime[keyIdx] = now;
          lastKeyEvent[keyIdx] = now;
        }
      } else if (!pressed && keyState[keyIdx]) {
        keyState[keyIdx] = false;
        lastKeyEvent[keyIdx] = now;

        if (!keyWasHeld[keyIdx]) {
          onKeyShortPress(keyIdx);
        }
        keyHeld[keyIdx]    = false;
        keyWasHeld[keyIdx] = false;
        keyPressTime[keyIdx] = 0;
      }

      if (keyState[keyIdx] && !keyHeld[keyIdx]) {
        if (now - keyPressTime[keyIdx] > LONG_PRESS_MS) {
          keyHeld[keyIdx] = true;
        }
      }
    }
  }

  for (int i = 0; i < 3; i++)
    pinMode(rowPins[i], INPUT_PULLUP);
}

void onKeyShortPress(int key) {
  switch (key) {
    case KEY_VOL:
      isMuted = !isMuted;
      si4735.setVolume(isMuted ? 0 : volume);
      showStatus();
      break;

    case KEY_AUDIO:
      toggleAudio();
      showStatus();
      break;

    case KEY_AGC:
      disableAgc = !disableAgc;
      si4735.setAutomaticGainControl(disableAgc, 1);
      showStatus();
      break;

    case KEY_BW:
      applyNextBandwidth(1);
      showStatus();
      break;

    case KEY_BFO:
      currentBFO = 0;
      si4735.setSSBBfo(0);
      showStatus();
      break;

    case KEY_SEEK:
      si4735.seekStationUp();
      delay(300);
      currentFreq = si4735.getCurrentFrequency();
      showStatus();
      break;
  }
}

void applyNextBandwidth(int delta) {
  if (currentMode == LSB || currentMode == USB) {
    bwIdxSSB = (bwIdxSSB + delta + 6) % 6;
    si4735.setSSBAudioBandwidth(bwIdxSSB);
    si4735.setSSBSidebandCutoffFilter(
      (bwIdxSSB == 0 || bwIdxSSB == 4 || bwIdxSSB == 5) ? 0 : 1);
  } else if (currentMode == AM) {
    bwIdxAM = (bwIdxAM + delta + 7) % 7;
    si4735.setBandwidth(bwIdxAM, 1);
  }
}

void setAntenna() {
  if (band[bandIdx].bandType == FM_BAND_TYPE ||
      band[bandIdx].bandType == SW_BAND_TYPE) {
    digitalWrite(ant_switch, HIGH);
  } else {
    digitalWrite(ant_switch, LOW);
  }
}

void setSpeaker() {
  digitalWrite(headphone_enable, LOW);
  delay(20);
  digitalWrite(speaker_enable, HIGH);
  currentOutput = OUTPUT_SPEAKER;
}

void setHeadphone() {
  digitalWrite(speaker_enable, LOW);
  delay(20);
  digitalWrite(headphone_enable, HIGH);
  currentOutput = OUTPUT_HEADPHONE;
}

void toggleAudio() {
  (currentOutput == OUTPUT_SPEAKER) ? setHeadphone() : setSpeaker();
}

void loadSSB() {
  display.clearDisplay();
  display.setTextSize(1);
  display.setCursor(0, 28);
  display.print(" Loading SSB patch..");
  display.display();
  si4735.reset();
  si4735.queryLibraryId();
  si4735.patchPowerUp();
  delay(50);
  si4735.setI2CFastMode();
  si4735.downloadPatch(ssb_patch_content, size_content);
  si4735.setI2CStandardMode();
  si4735.setSSBConfig(bwIdxSSB, 1, 0, 0, 0, 1);
  delay(25);
  ssbLoaded = true;
}

void useBand() {
  if (band[bandIdx].bandType == FM_BAND_TYPE) {
    currentMode = FM;
    si4735.setTuneFrequencyAntennaCapacitor(0);
    si4735.setFM(band[bandIdx].minimumFreq, band[bandIdx].maximumFreq,
                 band[bandIdx].currentFreq, band[bandIdx].currentStep);
    ssbLoaded = false;
  } else {
    si4735.setTuneFrequencyAntennaCapacitor(
      (band[bandIdx].bandType == MW_BAND_TYPE ||
       band[bandIdx].bandType == LW_BAND_TYPE) ? 0 : 1);

    if (ssbLoaded) {
      si4735.setSSB(band[bandIdx].minimumFreq, band[bandIdx].maximumFreq,
                    band[bandIdx].currentFreq, band[bandIdx].currentStep, currentMode);
      si4735.setSSBAutomaticVolumeControl(1);
      si4735.setSsbSoftMuteMaxAttenuation(0);
    } else {
      currentMode = AM;
      si4735.setAM(band[bandIdx].minimumFreq, band[bandIdx].maximumFreq,
                   band[bandIdx].currentFreq, band[bandIdx].currentStep);
      si4735.setAutomaticGainControl(1, 0);
      si4735.setAmSoftMuteMaxAttenuation(0);
    }
  }
  delay(100);
  currentFreq = previousFreq = band[bandIdx].currentFreq;
  currentStep = band[bandIdx].currentStep;
  si4735.setVolume(volume);
  setAntenna();
  showStatus();
}

void nextBand() {
  band[bandIdx].currentFreq = currentFreq;
  band[bandIdx].currentStep = currentStep;
  bandIdx = (bandIdx < lastBand) ? bandIdx + 1 : 0;
  useBand();
}

void cycleMode() {
  if (band[bandIdx].bandType == FM_BAND_TYPE) return;
  if (currentMode == AM) {
    loadSSB();
    currentMode = LSB;
  } else if (currentMode == LSB) {
    currentMode = USB;
  } else if (currentMode == USB) {
    currentMode = AM;
    ssbLoaded = false;
    currentBFO = 0;
  }
  band[bandIdx].currentFreq = currentFreq;
  band[bandIdx].currentStep = currentStep;
  useBand();
}

void showFrequency() {
  display.fillRect(0, 14, 128, 30, BLACK);
  display.setTextColor(WHITE);
  display.setTextSize(3);
  display.setCursor(0, 16);

  if (band[bandIdx].bandType == FM_BAND_TYPE) {
    display.print(currentFreq / 100);
    display.print(".");
    display.print((currentFreq % 100) / 10);
  } else {
    display.print(currentFreq);
  }

  display.setTextSize(1);
  display.setCursor(100, 16);
  display.print(band[bandIdx].bandType == FM_BAND_TYPE ? "MHz" : "kHz");
}

void showStatus() {
  display.clearDisplay();

  display.setTextSize(1);
  display.setCursor(0, 0);
  display.print(bandModeDesc[currentMode]);

  display.setCursor(25, 0);
  display.print("B:");
  display.print(bandIdx);

  if (currentMode == FM) {
    display.setCursor(50, 0);
    display.print(si4735.getCurrentPilot() ? "ST" : "MO");
  }

  display.setCursor(68, 0);
  display.print(disableAgc ? "   " : "AGC");

  display.setCursor(90, 0);
  display.print(currentOutput == OUTPUT_SPEAKER ? "SP" : "HP");

  display.setCursor(100, 0);
  display.print(battPercent);
  display.print("%");

  showFrequency();

  display.setTextSize(1);

  display.setCursor(0, 47);
  display.print("SIG:");
  int bars = constrain((rssi / 10) + 1, 0, 8);
  for (int i = 0; i < bars; i++) display.print("=");

  display.setCursor(0, 56);
  display.print("STP:");
  display.print(currentStep);
  display.print("k");

  display.setCursor(55, 56);
  if (isMuted) {
    display.print("MUTED");
  } else {
    display.print("VOL:");
    display.print(volume);
  }

  display.setCursor(55, 47);
  display.print("BW:");
  if (currentMode == LSB || currentMode == USB)
    display.print(bandwidthSSB[bwIdxSSB]);
  else if (currentMode == AM)
    display.print(bandwidthAM[bwIdxAM]);
  else
    display.print("--");

  if (currentMode == LSB || currentMode == USB) {
    display.setCursor(90, 56);
    display.print("B:");
    display.print(currentBFO);
  }

  display.display();
}

void handleEncoder() {
  long newPos = knob.read() / 4;
  if (newPos == encoderOldPos) return;
  encoderDelta  = (newPos > encoderOldPos) ? 1 : -1;
  encoderOldPos = newPos;

  if (keyHeld[KEY_VOL]) {
    keyWasHeld[KEY_VOL] = true;
    volume = constrain(volume + encoderDelta, 0, 63);
    if (isMuted) { isMuted = false; }
    si4735.setVolume(volume);
    showStatus();
    return;
  }

  if (keyHeld[KEY_BFO]) {
    keyWasHeld[KEY_BFO] = true;
    if (currentMode == LSB || currentMode == USB) {
      currentBFO += encoderDelta * 25;
      si4735.setSSBBfo(currentBFO);
      showStatus();
    }
    return;
  }

  if (keyHeld[KEY_BW]) {
    keyWasHeld[KEY_BW] = true;
    applyNextBandwidth(encoderDelta);
    showStatus();
    return;
  }

  if (encoderDelta == 1) si4735.frequencyUp();
  else                   si4735.frequencyDown();
  currentFreq = si4735.getCurrentFrequency();
  showFrequency();
  display.display();
}

void handleEncoderClick() {
  unsigned long now = millis();
  if (digitalRead(encoder_sw) == LOW && (now - lastEncClick) > 300) {
    lastEncClick = now;
    if (keyHeld[KEY_AGC]) {
      keyWasHeld[KEY_AGC] = true;
      cycleMode();
    } else {
      nextBand();
    }
  }
}

void readBattery() {
  int raw = analogRead(batt_read);
  float adcVoltage = (raw / ADC_RES) * ADC_VREF;
  battVoltage = adcVoltage * ((BATT_R1 + BATT_R2) / (float)BATT_R2);
  battVoltage = constrain(battVoltage, BATT_MIN, BATT_MAX);
  battPercent = (uint8_t)(((battVoltage - BATT_MIN) / (BATT_MAX - BATT_MIN)) * 100.0);
}

void setup() {
  Serial.begin(115200);

  Wire.setSDA(sda_oled);
  Wire.setSCL(scl_oled);
  Wire.begin();

  Wire1.setSDA(sda_ic);
  Wire1.setSCL(scl_ic);
  Wire1.begin();
  Wire1.setClock(100000);

  pinMode(batt_read, INPUT);

  analogReadResolution(12);
  readBattery();
  pinMode(COL1, INPUT_PULLUP);
  pinMode(COL2, INPUT_PULLUP);
  for (int i = 0; i < 3; i++)
    pinMode(rowPins[i], INPUT_PULLUP);
  pinMode(encoder_sw,       INPUT_PULLUP);
  pinMode(speaker_enable,   OUTPUT);
  pinMode(headphone_enable, OUTPUT);
  pinMode(ant_switch,       OUTPUT);

  setSpeaker();
  setAntenna();

  if (!display.begin(SSD1306_SWITCHCAPVCC, OLED_ADDR)) {
    Serial.println(F("SSD1306 not found"));
    for (;;);
  }
  display.clearDisplay();
  display.setTextColor(WHITE);
  display.setTextSize(2);
  display.setCursor(10, 10);
  display.println("Akash");
  display.setTextSize(1);
  display.setCursor(10, 35);
  display.println("Chowa DX Receiver");
  display.display();
  delay(2000);

  si4735.setDeviceI2CAddress(0x11);
  si4735.setup(rst_ic, -1, SI473X_ANALOG_AUDIO, Wire1);
  si4735.setFM(band[0].minimumFreq, band[0].maximumFreq,
               band[0].currentFreq, band[0].currentStep);
  currentFreq = previousFreq = si4735.getCurrentFrequency();
  si4735.setVolume(volume);
  showStatus();
}

void loop() {
  scanMatrix();
  handleEncoder();
  handleEncoderClick();

  if (currentFreq != previousFreq) {
    previousFreq = currentFreq;
    band[bandIdx].currentFreq = currentFreq;
  }

  if (currentBFO != previousBFO) {
    previousBFO = currentBFO;
    si4735.setSSBBfo(currentBFO);
  }

  if (millis() - lastRSSITime > RSSI_INTERVAL) {
    si4735.getCurrentReceivedSignalQuality();
    rssi = si4735.getCurrentRSSI();
    lastRSSITime = millis();
    
    showStatus();
  }
  if (millis() - lastBattTime > BATT_INTERVAL) {
    readBattery();
    lastBattTime = millis();
  }

  delay(10);
}

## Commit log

2025-11-05 Update Radio.kicad_sch
    Did basic Schematic
    [Radio.kicad_sch]
2025-11-06 prepped the base PCB
    This is my 1st RF pcb so I just did the placement for now
    I am gonna consult an engineer later to see what I have wrong
    [Radio.kicad_pcb, Radio.kicad_sch]
2025-11-10 Update PCB: move components
    Moved several components to new positions. and changed potentiometer footprint
    [Radio.kicad_pcb, Radio.kicad_sch]
2025-11-12 Update PCB layout and footprints
    [Radio.kicad_pcb, Radio.kicad_sch]
2026-05-13 Update README
    Added a brief description about the PCB status.
2026-05-19 Updated PCB
    [Radio.kicad_pcb, Radio.kicad_sch]
2026-05-21 push to git
    [Radio.kicad_pcb, Radio.kicad_sch]
2026-05-28 Pushing stuff
    [Akash Chowa DX base Case.3mf, Akash Chowa DX.kicad_pcb, Akash Chowa DX.kicad_sch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]
2026-05-28 Adding More parts to the BOM
    [Akash Chowa DX.kicad_pcb, Akash Chowa DX.kicad_sch]
2026-05-28 Finished Adding all parts to Bom
    [Akash Chowa DX.kicad_pcb]
2026-05-28 Added bom.csv
    [Akash_Chowa_DX_bom.csv, Akash_Chowa_DX_designators.csv, Akash_Chowa_DX_positions.csv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]
2026-05-28 Exporter Gerber again
    [Akash_Chowa_DX_bom.csv, Akash_Chowa_DX_positions.csv]
2026-05-28 Fully finishing everything
    [Radio Top.step, Radio battery Cover.step, bom.csv]
2026-05-28 Add knob file
    [Knob Cap.step]
2026-05-30 Adding new stuff after changing PCB size
    [Akash Chowa Battery Cover.step, Akash Chowa DX base Case.3mf, Akash Chowa DX.kicad_pcb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]
